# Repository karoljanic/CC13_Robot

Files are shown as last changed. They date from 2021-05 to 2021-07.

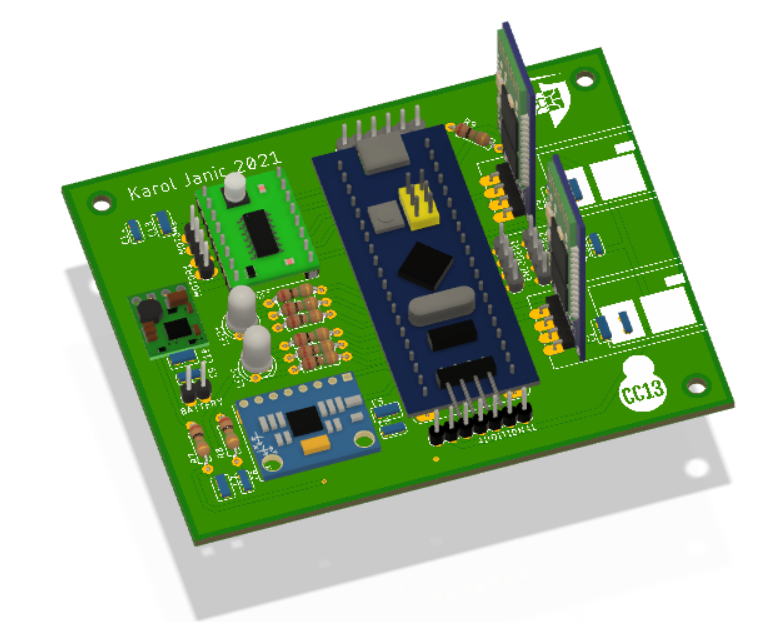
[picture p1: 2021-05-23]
CC13_ELECTRONICS/3DView.PNG

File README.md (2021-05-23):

# CC13_Robot
This is a robot project modeled on BB8. 
The construction is modelled in Autodesk Fusion 360 and printed using 3D printing technology. I currently use Creality Ender 3. 
The electronics is based on the STM21F1038C and self-made PCB / Arduino Nano 33 BLE Sense processor. 
The robot is controlled by a mobile app via Bluetooth. It is developed in Android Studio. 
Work still in progress.

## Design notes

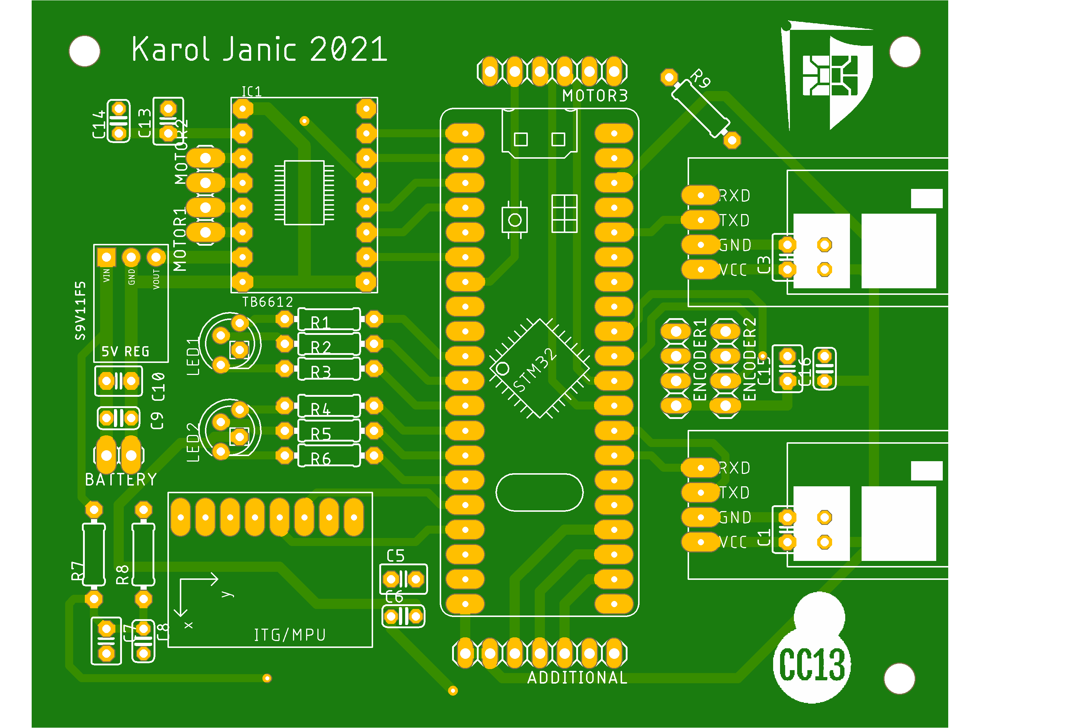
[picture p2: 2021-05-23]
CC13_ELECTRONICS/CC13.png

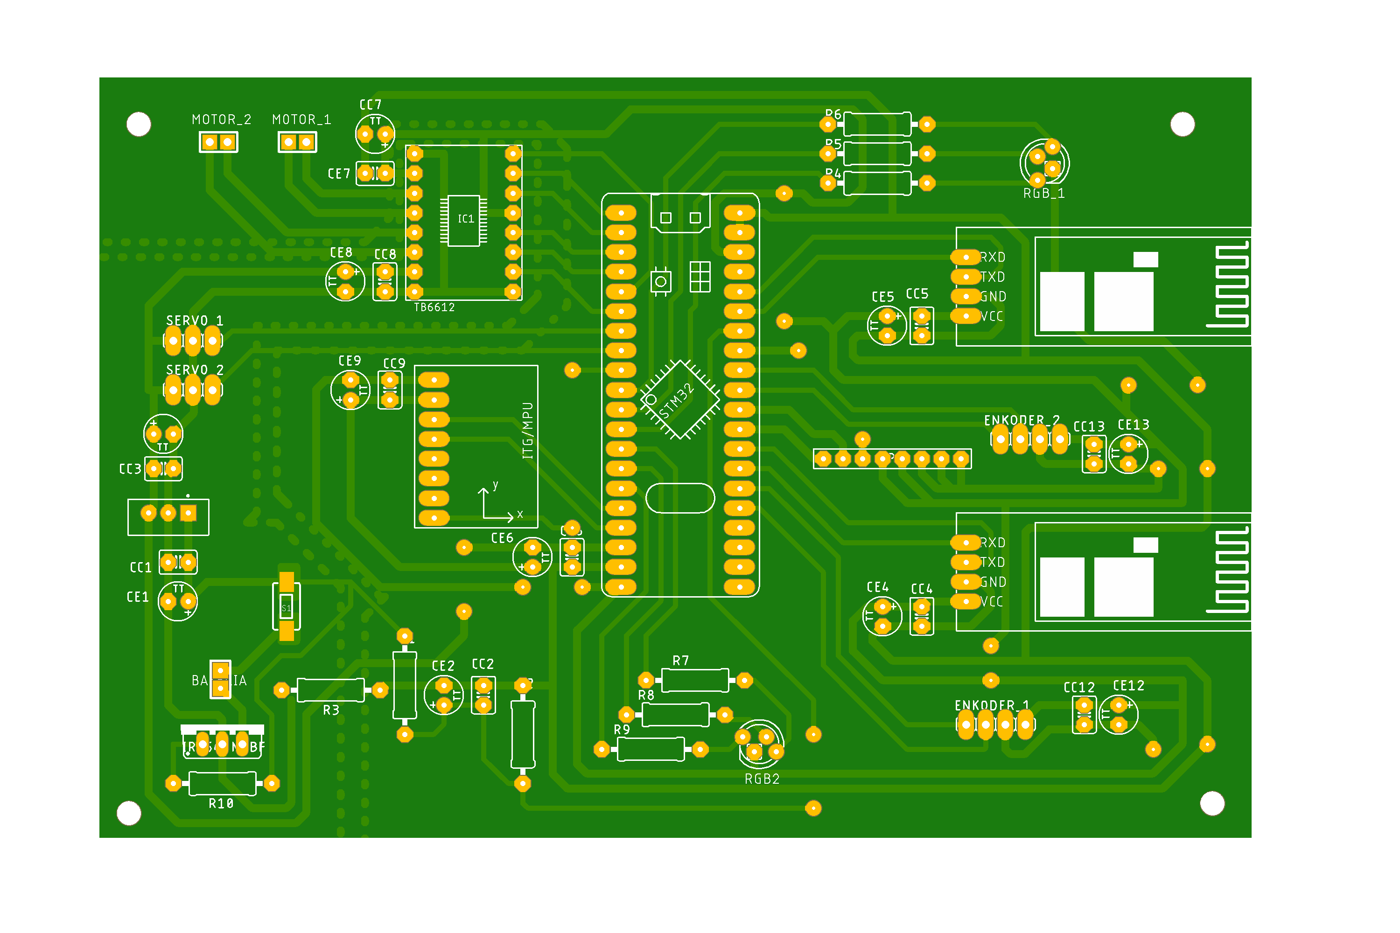
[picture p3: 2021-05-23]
CC13_ELECTRONICS/dokumenty/ModelPłytki.png

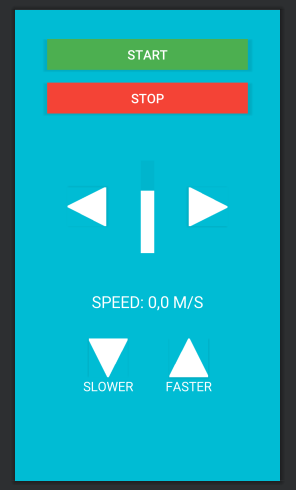
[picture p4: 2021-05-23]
CC13_MOBILE_APP/screeny_aplikacji/aplikacja_screen6.PNG

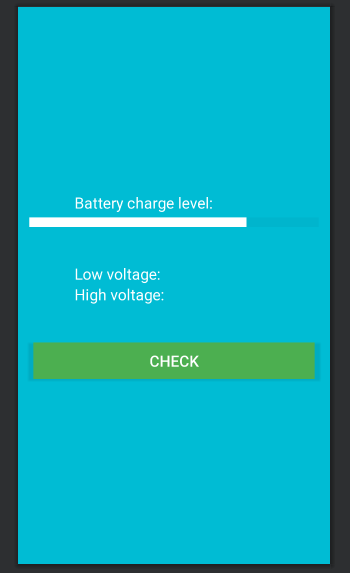
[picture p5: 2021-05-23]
CC13_MOBILE_APP/screeny_aplikacji/aplikacja_screen1.PNG

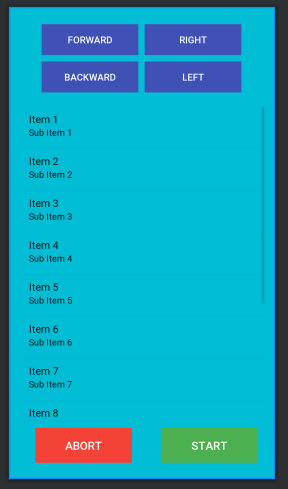
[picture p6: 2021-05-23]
CC13_MOBILE_APP/screeny_aplikacji/aplikacja_screen5.PNG

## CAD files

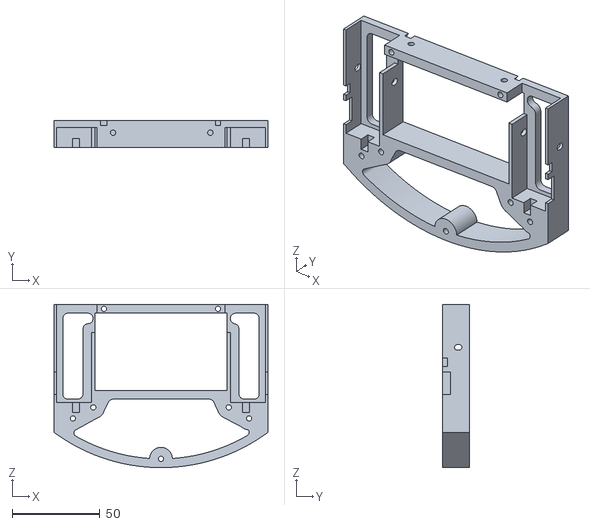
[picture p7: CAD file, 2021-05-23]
CC13_MECHANICS/CC13v7/part.1.II.v.7.stl
122.0 x 15.5 x 93.0

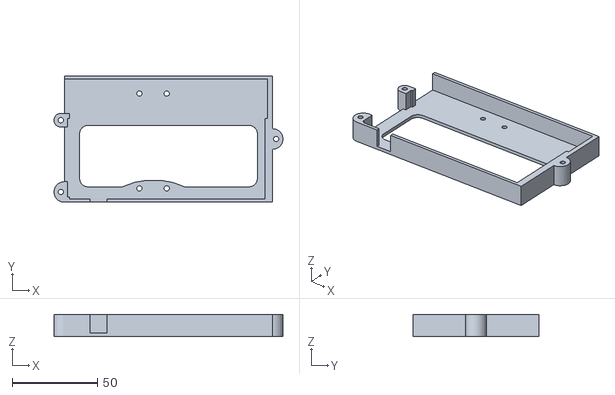
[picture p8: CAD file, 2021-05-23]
CC13_MECHANICS/CC13v7/part.1.c.I.v.7.stl
134.0 x 74.0 x 13.0

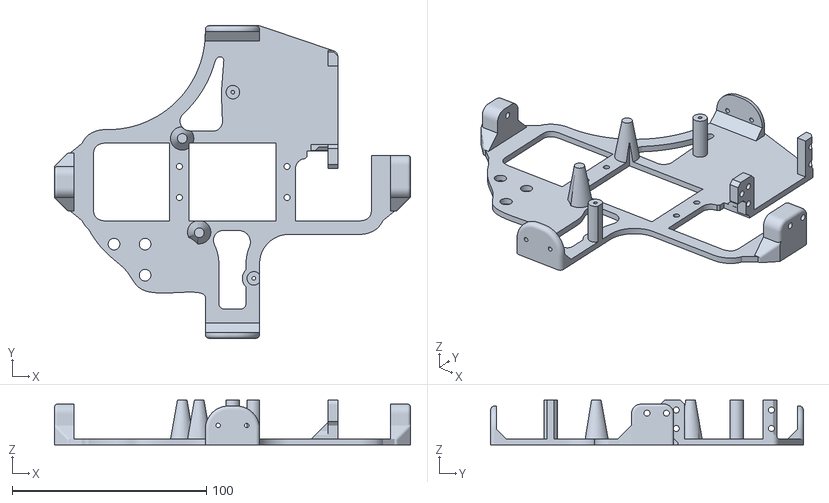
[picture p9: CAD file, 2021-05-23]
CC13_MECHANICS/CC13v7/part3.v.7.stl
183.3 x 161.0 x 23.0

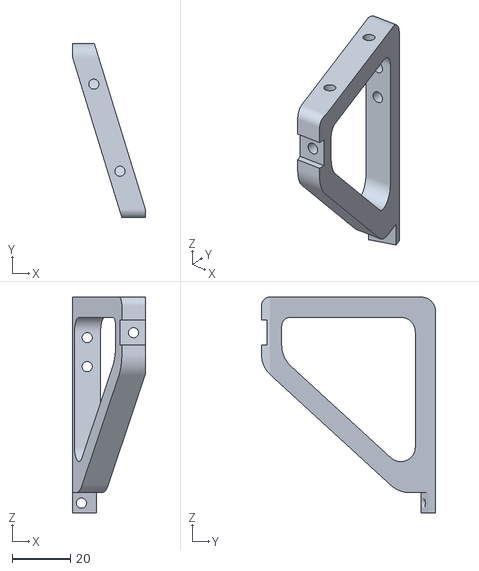
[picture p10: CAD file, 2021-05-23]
CC13_MECHANICS/CC13v7/okov6.stl
25.0 x 60.0 x 74.4

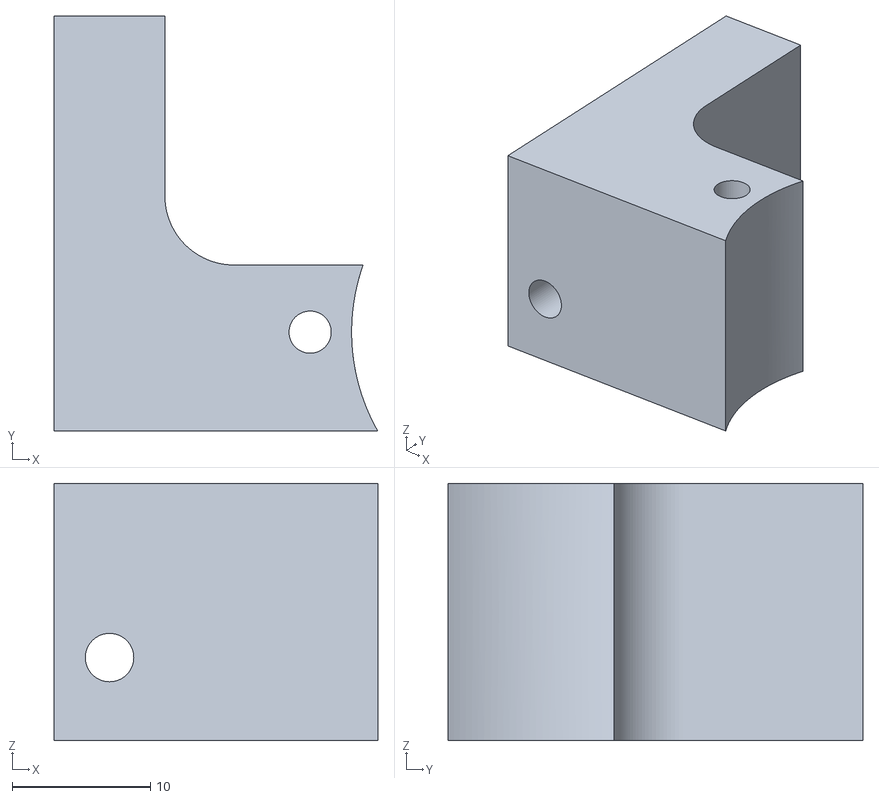
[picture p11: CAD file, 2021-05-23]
CC13_MECHANICS/CC13v7/Body3.stl
23.4 x 30.0 x 18.6

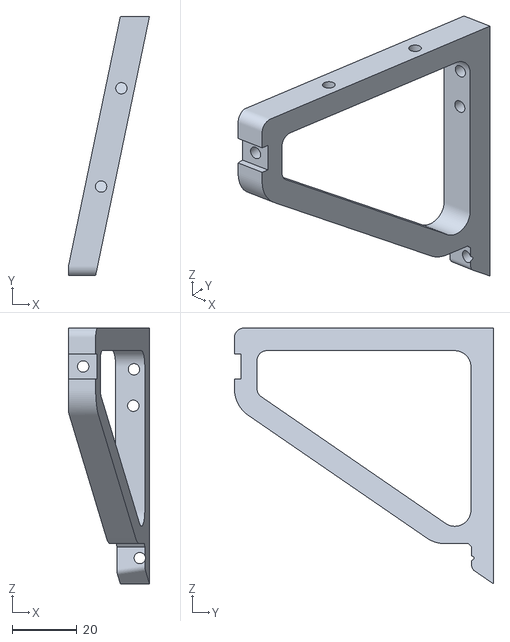
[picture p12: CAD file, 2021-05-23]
CC13_MECHANICS/CC13v7/Part2rev.stl
25.0 x 80.0 x 79.0

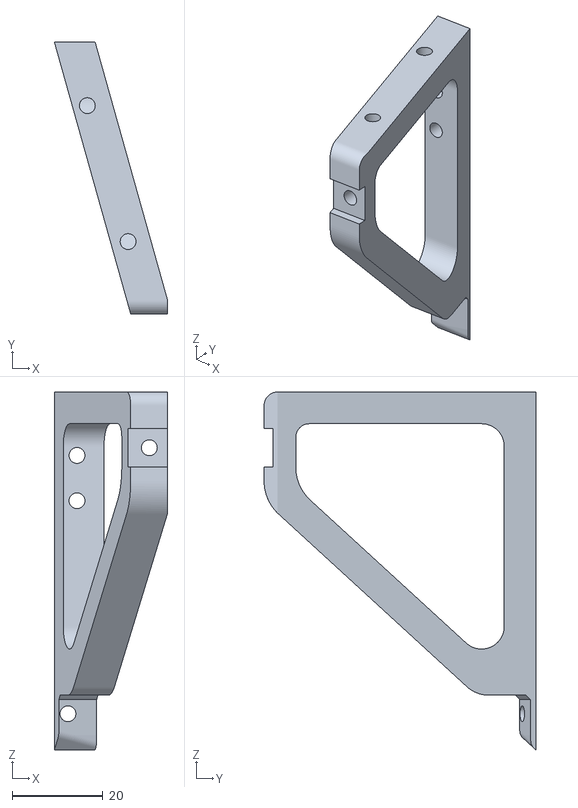
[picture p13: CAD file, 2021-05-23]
CC13_MECHANICS/CC13v7/Body1.stl
25.0 x 60.0 x 79.0

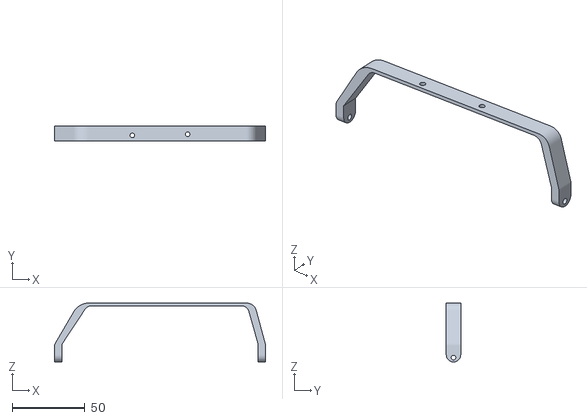
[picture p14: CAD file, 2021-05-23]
CC13_MECHANICS/CC13v7/part5.v.7.stl
145.0 x 10.0 x 40.5

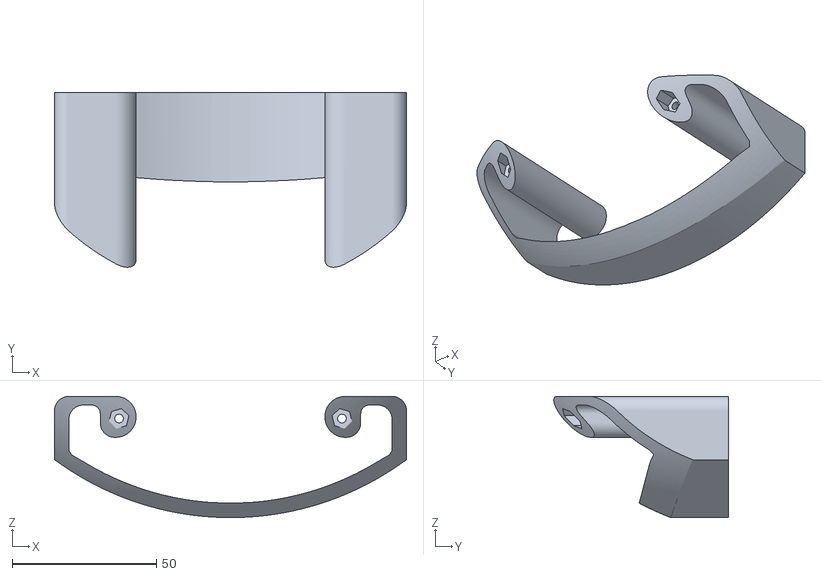
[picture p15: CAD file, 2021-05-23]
CC13_MECHANICS/CC13v7/part.4.v.7.stl
122.0 x 60.5 x 42.0

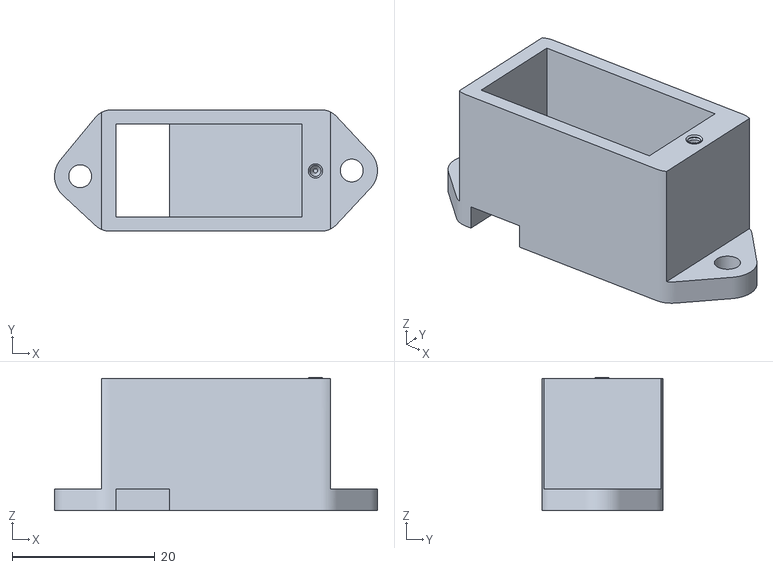
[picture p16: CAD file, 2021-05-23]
CC13_MECHANICS/CC13v7/part6.v.7.stl
45.2 x 17.0 x 18.6

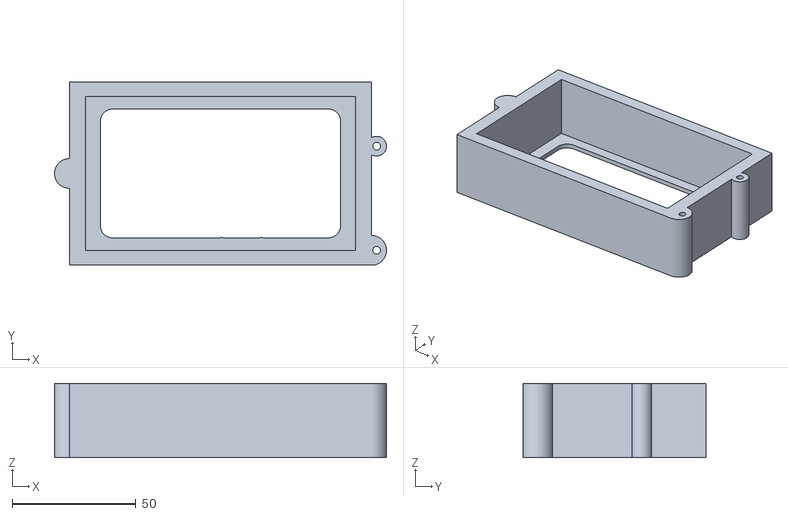
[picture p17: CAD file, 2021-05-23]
CC13_MECHANICS/CC13v7/part.1.c.II.v.7.stl
134.0 x 74.0 x 30.0

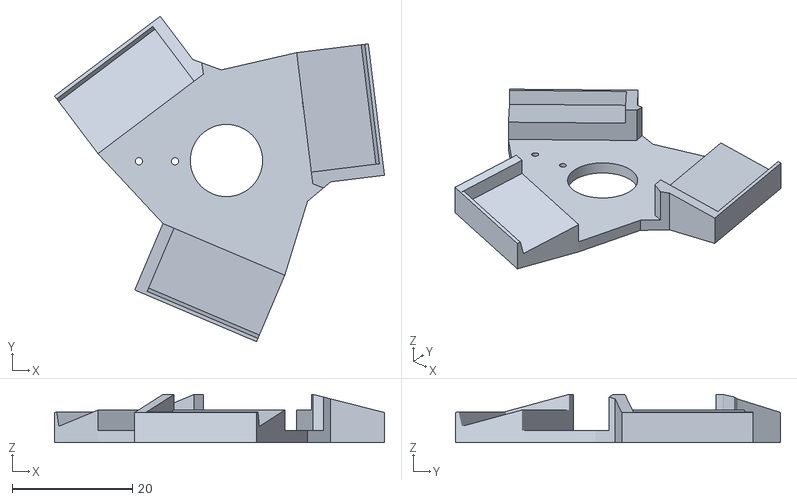
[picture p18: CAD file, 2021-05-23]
CC13_MECHANICS/CC13v7/part7.v.7.stl
54.8 x 54.1 x 8.00

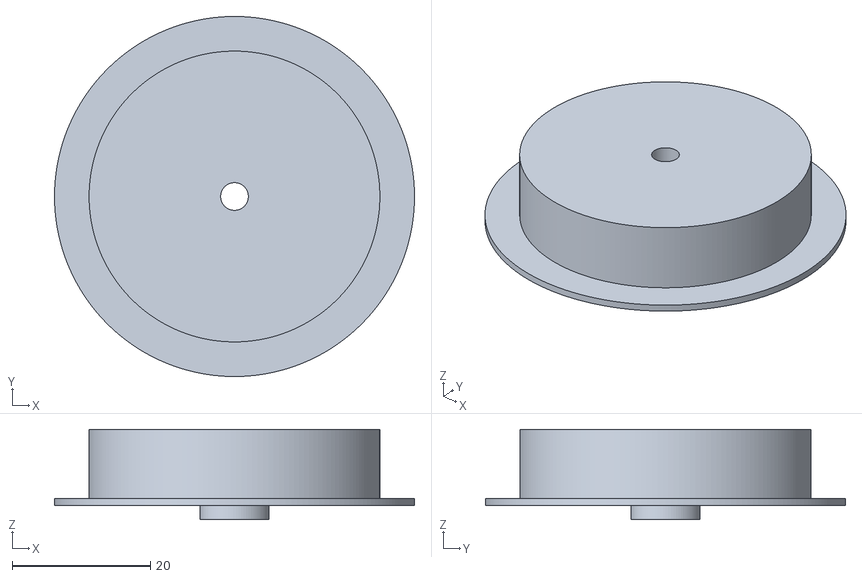
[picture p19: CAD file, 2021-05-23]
CC13_MECHANICS/CC13v7/felga.stl
52.0 x 52.0 x 13.0

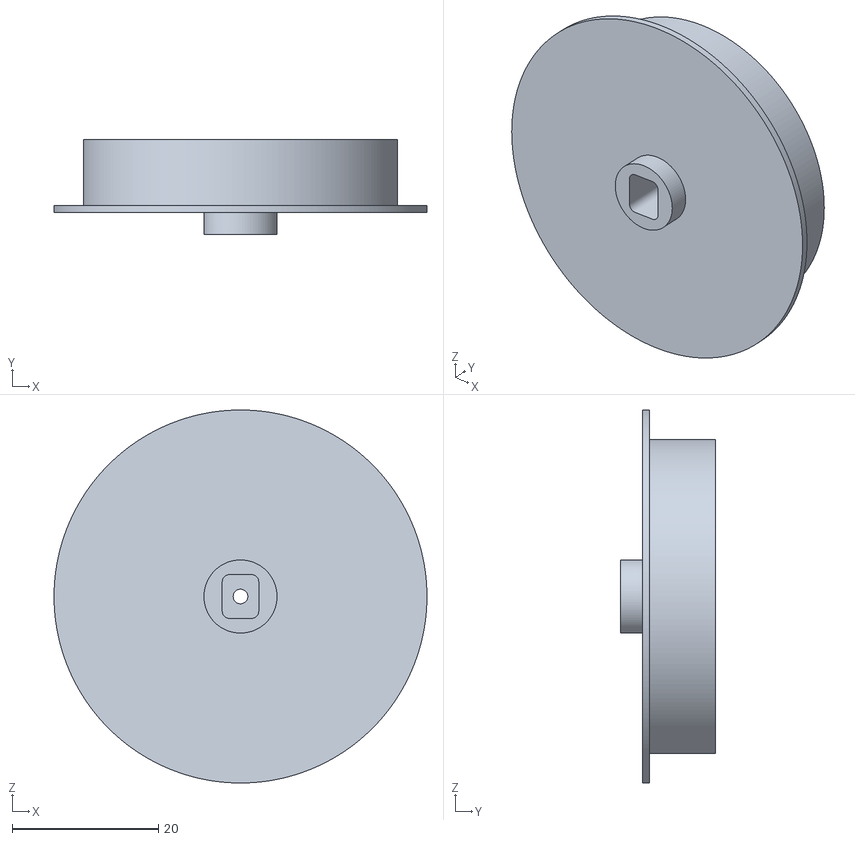
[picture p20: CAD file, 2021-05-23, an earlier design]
CC13_MECHANICS/CC13v7/part2.v.7.stl
51.0 x 13.0 x 51.0

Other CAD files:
CC13_MECHANICS/CC13v7/Body3rev.stl
CC13_MECHANICS/CC13v7/Part2 v16.stl
CC13_MECHANICS/CC13v7/Body2.stl
CC13_MECHANICS/CC13v7/part.1.I.v.7.stl

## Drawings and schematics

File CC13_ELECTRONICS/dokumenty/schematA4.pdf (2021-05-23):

## GND

## AGND

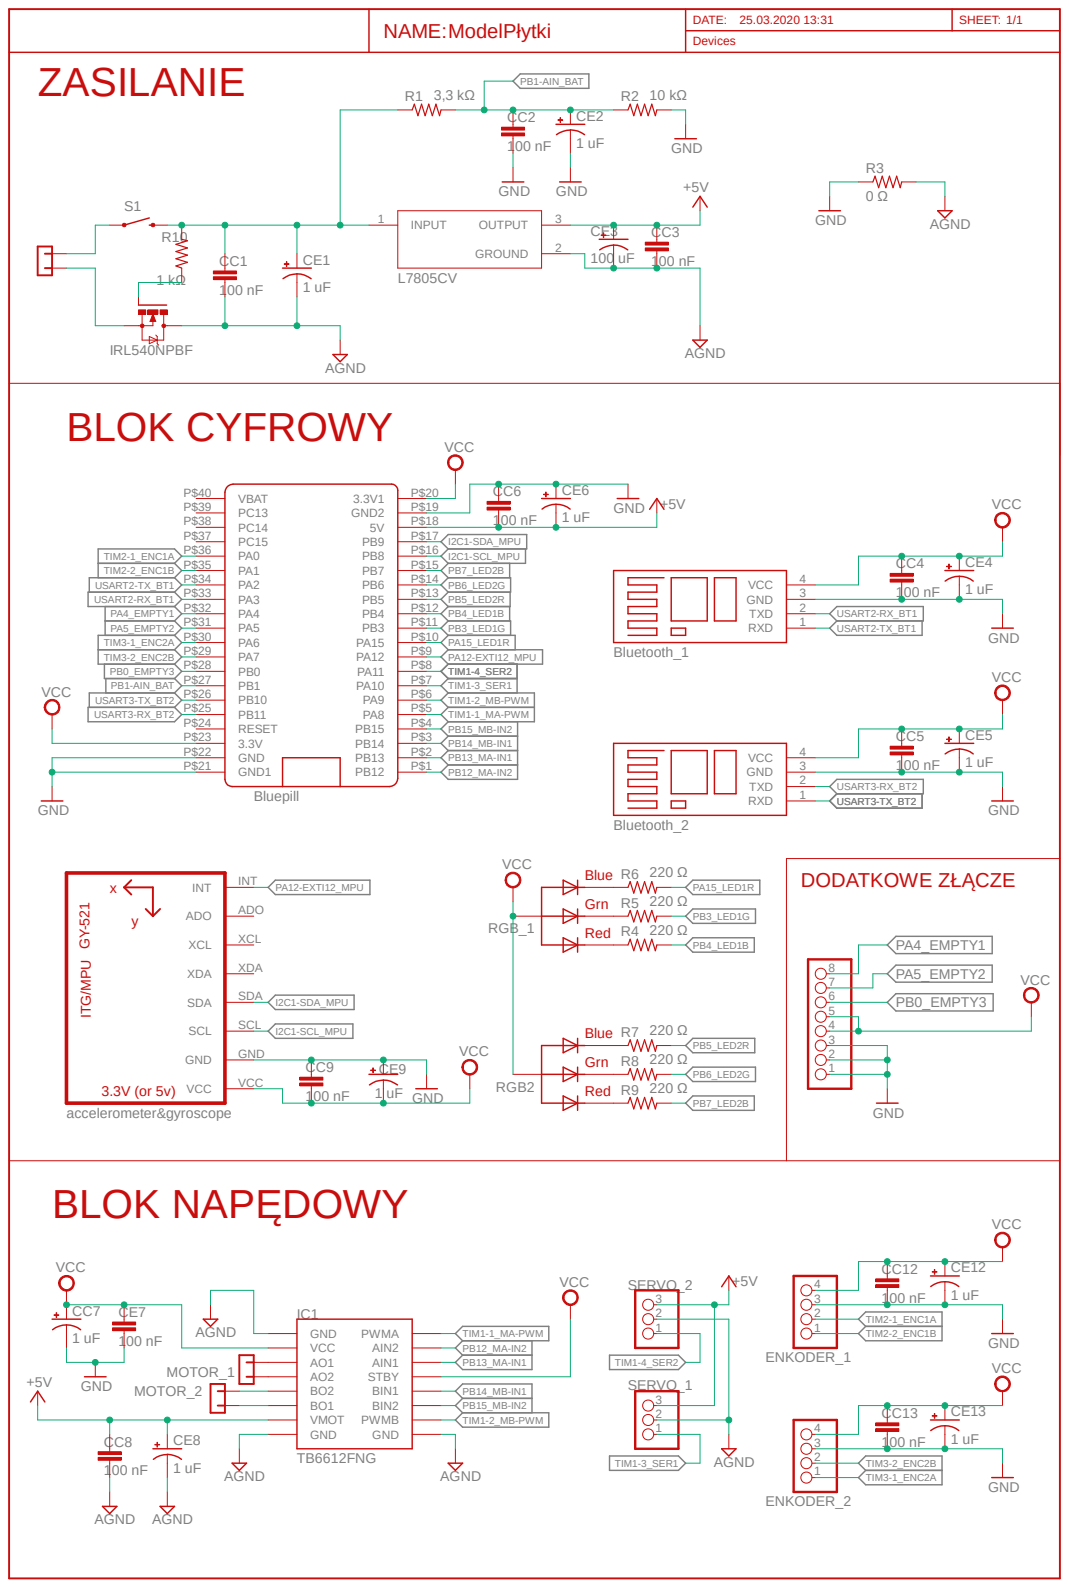
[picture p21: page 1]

DODATKOWE ZŁĄCZE GY⁻⁵²¹ ITG/MPU

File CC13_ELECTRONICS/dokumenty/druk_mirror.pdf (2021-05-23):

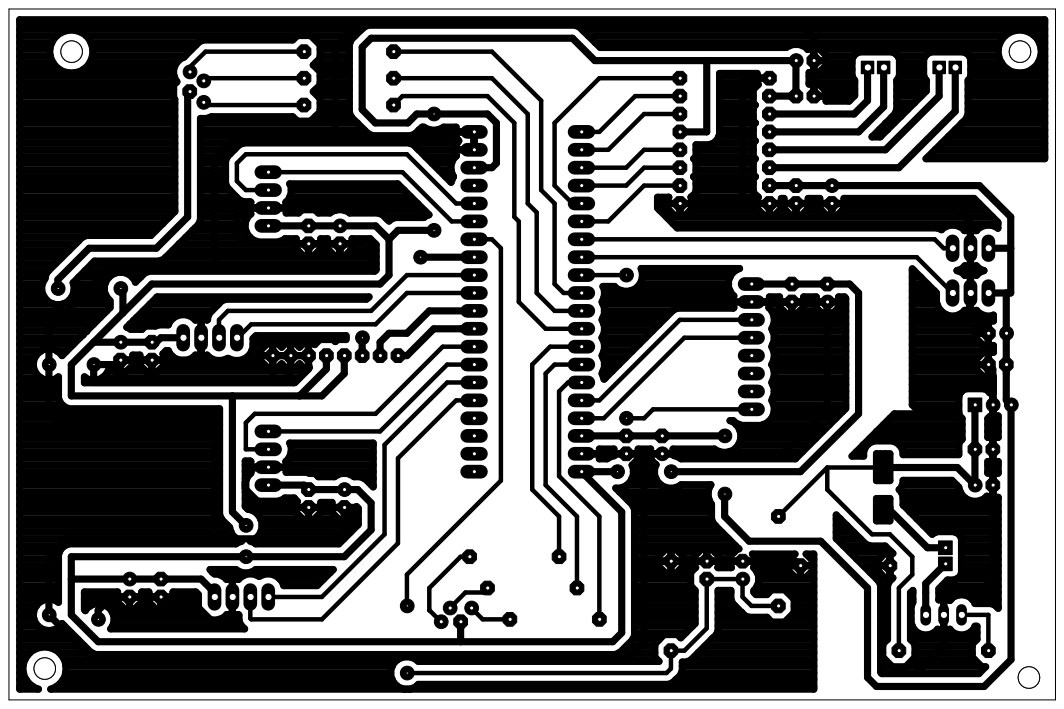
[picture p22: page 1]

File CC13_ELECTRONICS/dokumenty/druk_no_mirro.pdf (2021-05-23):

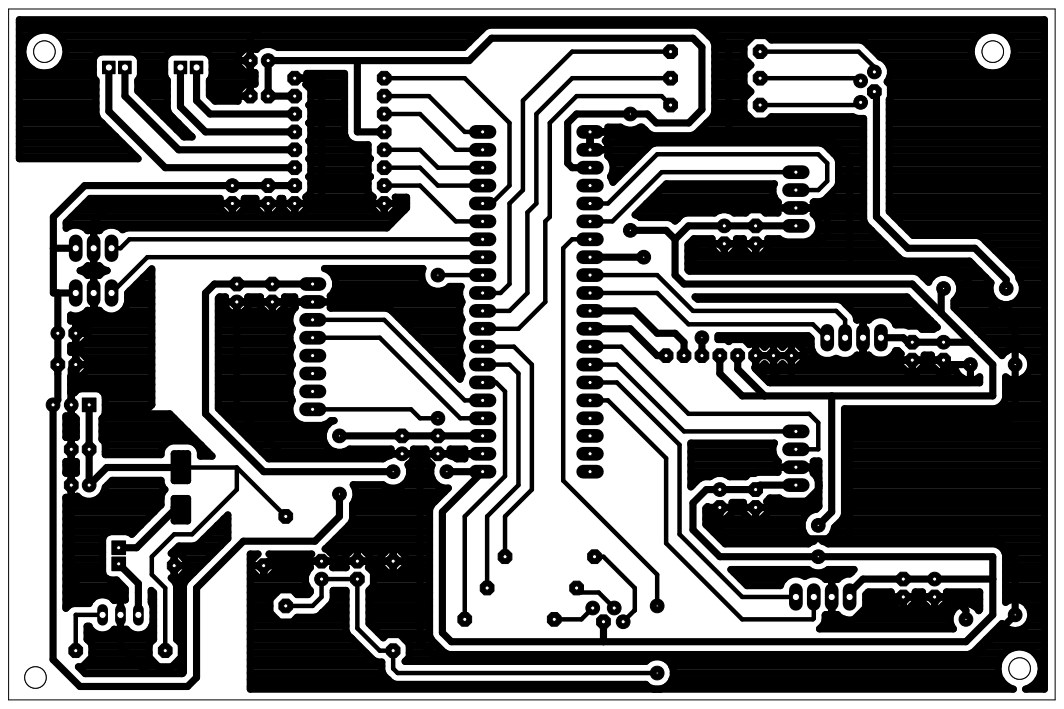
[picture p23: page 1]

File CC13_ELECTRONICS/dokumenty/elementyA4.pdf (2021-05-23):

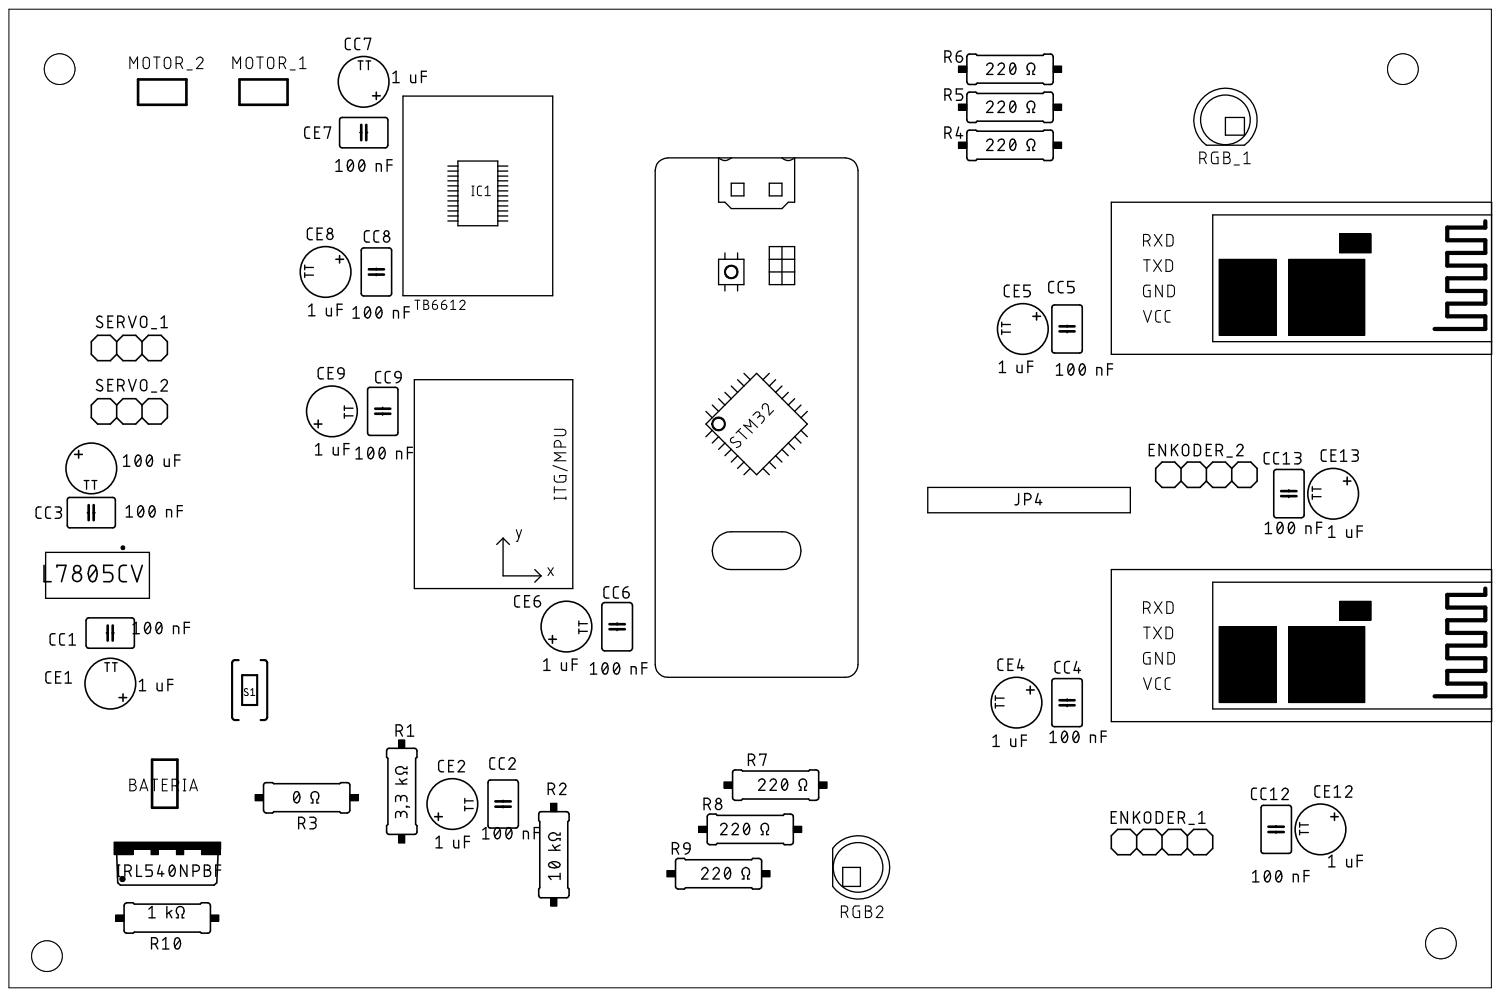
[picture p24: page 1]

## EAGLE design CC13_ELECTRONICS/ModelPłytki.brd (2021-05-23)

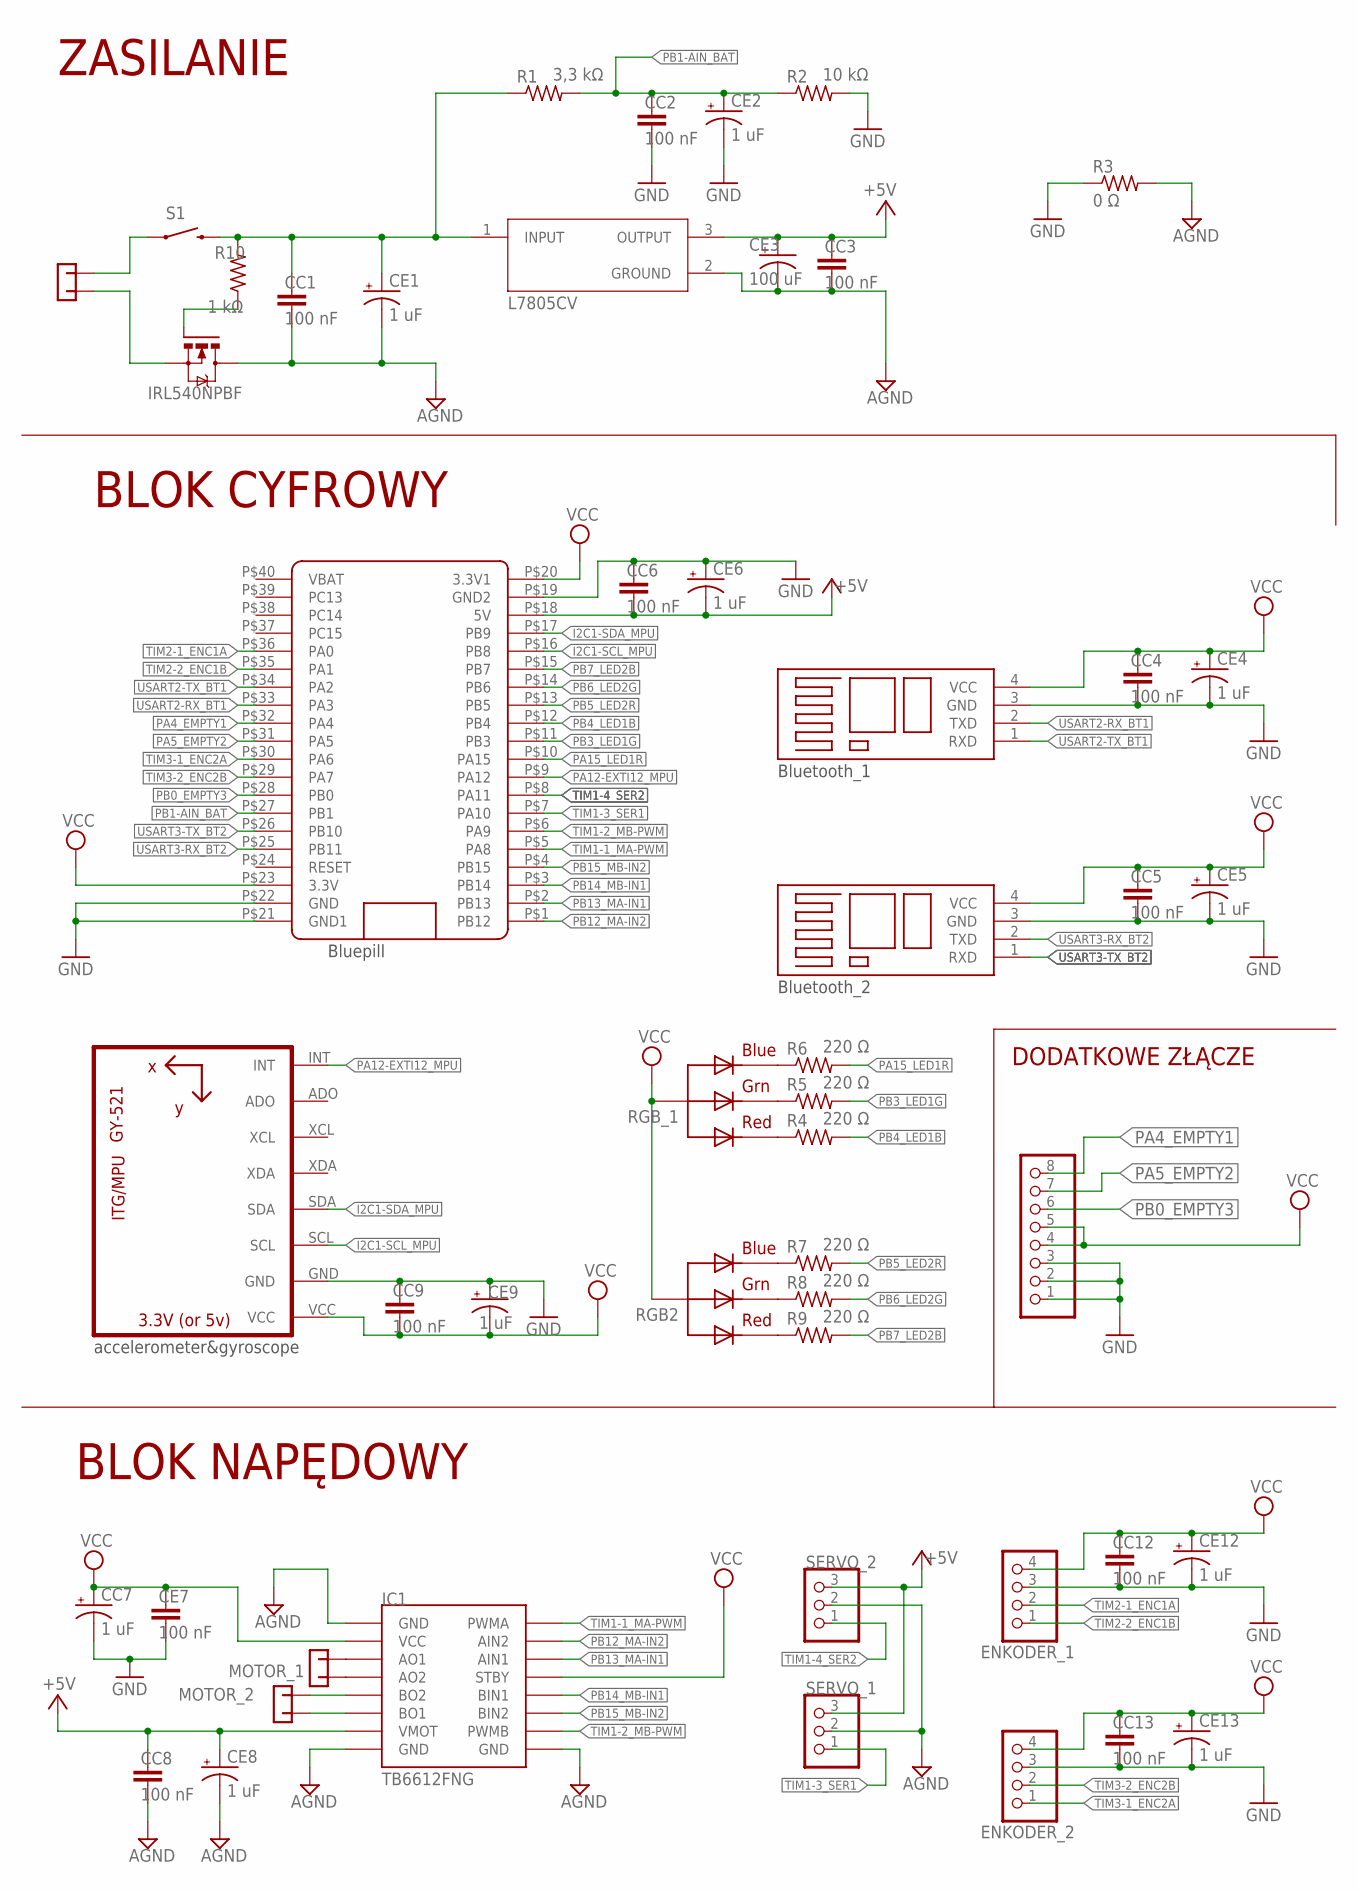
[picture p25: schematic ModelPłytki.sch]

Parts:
BATERIA: -CON2; CON2
BLUETOOTH2, BLUETOOTH3: BLUETOOTH
CC1, CC2, CC3, CC4, CC5, CC6, CC8, CC9, CC12, CC13: 100 nF; C025-030X050
CC7: 1 uF; TT2D5
CE1, CE2, CE4, CE5, CE6, CE8, CE9, CE12, CE13: 1 uF; TT2D5
CE3: 100 uF; TT2D5
CE7: 100 nF; C025-030X050
ENKODER_1, ENKODER_2: PINHD-1X4; 1X04
IC1: MODUL_POLOLU
IRL540NPBF: IRF520; TO220BV
JP4: PINHD-1X8BIG; 1X08-BIG
MOTOR_1, MOTOR_2: -CON2; CON2
R1: 3,3 kΩ; 0309/12
R2: 10 kΩ; 0309/12
R3: 0 Ω; 0309/12
R4, R5, R6, R7, R8, R9: 220 Ω; 0309/12
R10: 1 kΩ; 0309/12
RGB2: RGBLED_CA-5MM; LED5MMRGB
RGB_1: RGBLED_CA-5MM; LED5MMRGB
S1: RS032G05A3SM-SPST-MOMENTARY-SWSMD-1101NE; TACTILE-SWITCH-1101NE
SERVO_1, SERVO_2: PINHD-1X3; 1X03
U2: L7805CV; TO255P1040X460X1968-3
U4: GY-521MPU6050; GY-521
U$2: BLUE_PILL

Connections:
+5V: CC3.1, CC6.2, CC8.1, CE3.+, CE6.-, CE8.+, IC1.VMOT, SERVO_1.3, SERVO_2.3, U2.3 (OUTPUT), U$2.P$18 (5V)
AGND: CC1.2, CC3.2, CC8.2, CE1.-, CE3.-, CE8.-, IC1.GND1 (GND), IC1.GND2 (GND), IC1.GND3 (GND), IRL540NPBF.D, R3.2, SERVO_1.2, SERVO_2.2, U2.2 (GROUND)
GND: BLUETOOTH2.3 (GND), BLUETOOTH3.3 (GND), CC2.2, CC4.2, CC5.2, CC6.1, CC7.-, CC9.1, CC12.2, CC13.2, CE2.-, CE4.-, CE5.-, CE6.+, CE7.2, CE9.+, CE12.-, CE13.-, ENKODER_1.3, ENKODER_2.3, JP4.1, JP4.2, JP4.3, R2.2, R3.1, U4.GND, U$2.P$19 (GND2), U$2.P$21 (GND1), U$2.P$22 (GND)
I2C1-SCL_MPU: U4.SCL, U$2.P$16 (PB8)
I2C1-SDA_MPU: U4.SDA, U$2.P$17 (PB9)
unnamed: IRL540NPBF.G, R10.1
unnamed: IC1.BO2, MOTOR_2.P$1 (1)
unnamed: IC1.A02 (AO2), MOTOR_1.P$2 (2)
unnamed: IC1.BO1, MOTOR_2.P$2 (2)
unnamed: BATERIA.P$1 (1), S1.1
unnamed: R6.1, RGB_1.4 (BLUE)
unnamed: R5.1, RGB_1.3 (GREEN)
unnamed: R4.1, RGB_1.1 (RED)
unnamed: R8.1, RGB2.3 (GREEN)
unnamed: R7.1, RGB2.4 (BLUE)
unnamed: R9.1, RGB2.1 (RED)
unnamed: BATERIA.P$2 (2), IRL540NPBF.S
unnamed: IC1.AO1, MOTOR_1.P$1 (1)
unnamed: CC1.1, CE1.+, R1.1, R10.2, S1.2, U2.1 (INPUT)
PA4_EMPTY1: JP4.8, U$2.P$32 (PA4)
PA5_EMPTY2: JP4.7, U$2.P$31 (PA5)
PA12-EXTI12_MPU: U4.INT, U$2.P$9 (PA12)
PA15_LED1R: R6.2, U$2.P$10 (PA15)
PB0_EMPTY3: JP4.6, U$2.P$28 (PB0)
PB1-AIN_BAT: CC2.1, CE2.+, R1.2, R2.1, U$2.P$27 (PB1)
PB3_LED1G: R5.2, U$2.P$11 (PB3)
PB4_LED1B: R4.2, U$2.P$12 (PB4)
PB5_LED2R: R7.2, U$2.P$13 (PB5)
PB6_LED2G: R8.2, U$2.P$14 (PB6)
PB7_LED2B: R9.2, U$2.P$15 (PB7)
PB12_MA-IN2: IC1.AIN2, U$2.P$1 (PB12)
PB13_MA-IN1: IC1.AIN1, U$2.P$2 (PB13)
PB14_MB-IN1: IC1.BIN1, U$2.P$3 (PB14)
PB15_MB-IN2: IC1.BIN2, U$2.P$4 (PB15)
TIM1-1_MA-PWM: IC1.PWMA, U$2.P$5 (PA8)
TIM1-2_MB-PWM: IC1.PWMB, U$2.P$6 (PA9)
TIM1-3_SER1: SERVO_1.1, U$2.P$7 (PA10)
TIM1-4_SER2: SERVO_2.1, U$2.P$8 (PA11)
TIM2-1_ENC1A: ENKODER_1.2, U$2.P$36 (PA0)
TIM2-2_ENC1B: ENKODER_1.1, U$2.P$35 (PA1)
TIM3-1_ENC2A: ENKODER_2.1, U$2.P$30 (PA6)
TIM3-2_ENC2B: ENKODER_2.2, U$2.P$29 (PA7)
USART2-RX_BT1: BLUETOOTH2.2 (TXD), U$2.P$33 (PA3)
USART2-TX_BT1: BLUETOOTH2.1 (RXD), U$2.P$34 (PA2)
USART3-RX_BT2: BLUETOOTH3.2 (TXD), U$2.P$25 (PB11)
USART3-TX_BT2: BLUETOOTH3.1 (RXD), U$2.P$26 (PB10)
VCC: BLUETOOTH2.4 (VCC), BLUETOOTH3.4 (VCC), CC4.1, CC5.1, CC7.+, CC9.2, CC12.1, CC13.1, CE4.+, CE5.+, CE7.1, CE9.-, CE12.+, CE13.+, ENKODER_1.4, ENKODER_2.4, IC1.STBY, IC1.VCC, JP4.4, JP4.5, RGB2.2 (VCC), RGB_1.2 (VCC), U4.VCC, U$2.P$20 (3.3V1), U$2.P$23 (3.3V)

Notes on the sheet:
ZASILANIE
BLOK CYFROWY
BLOK NAPĘDOWY
Bluetooth_1
Bluetooth_2
Bluepill
accelerometer&gyroscope
DODATKOWE ZŁĄCZE

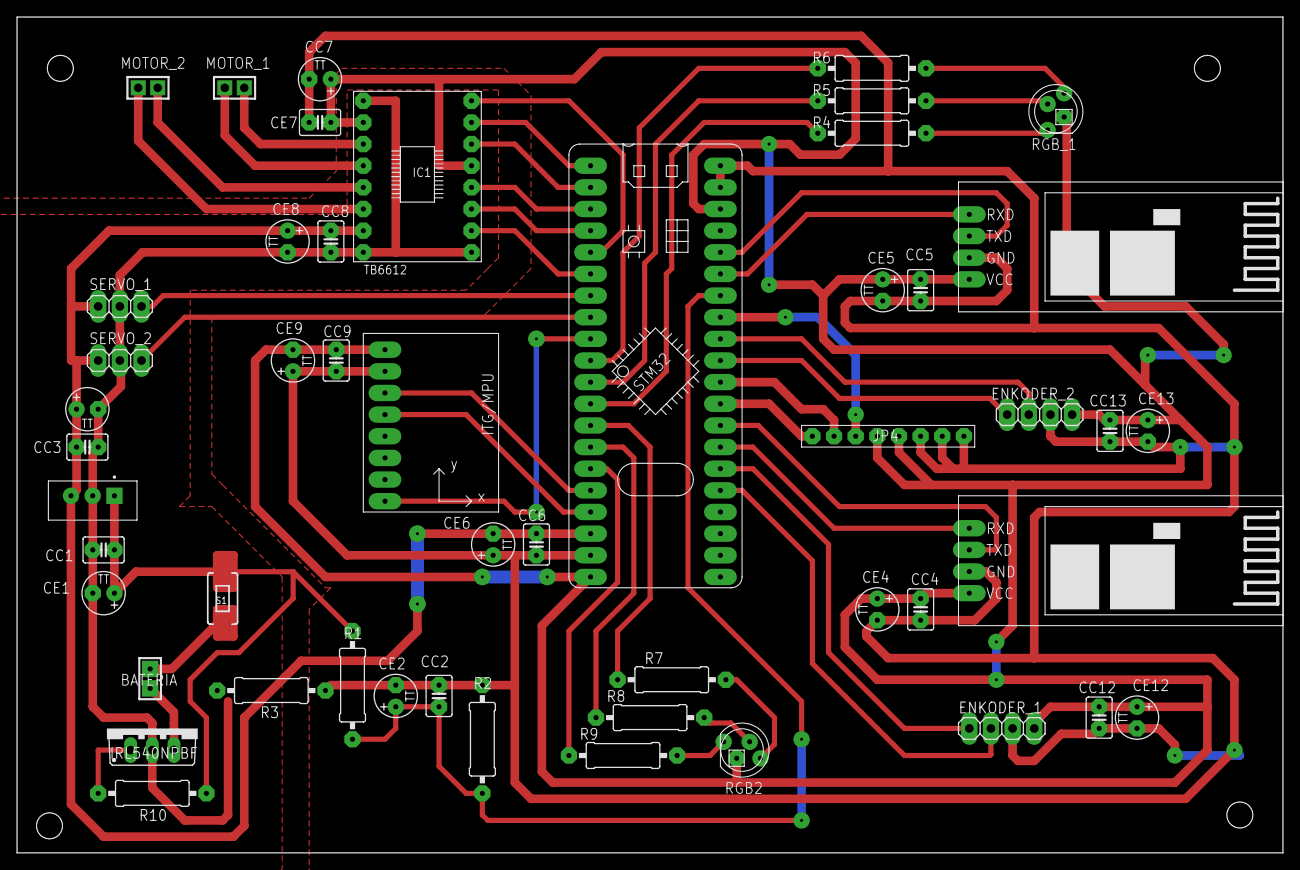
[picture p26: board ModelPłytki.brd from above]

Board: 2 copper layers, 148.6 x 98.1 mm, 50 parts (0 on the bottom side), 47 nets.

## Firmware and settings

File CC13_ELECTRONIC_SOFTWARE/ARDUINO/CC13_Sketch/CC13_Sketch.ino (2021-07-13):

#include <ArduinoBLE.h>       // Bluetooth Low Energy
#include <Arduino_LSM9DS1.h>  // Accelerometer, Gyroscope, Magnetometer
#include <Arduino_HTS221.h>   // Thermometer, Humidity meter 

// define used pins 
#define MOTOR_PWM_A    P0_4
#define MOTOR_PWM_B    P0_5
#define MOTOR_IN_1_A   P1_11
#define MOTOR_IN_2_A   P1_12
#define MOTOR_IN_1_B   P1_15
#define MOTOR_IN_2_B   P1_13

#define ENCODER_INC_A  P1_14
#define ENCODER_DEC_A  P0_30
#define ENCODER_INC_B  P0_23
#define ENCODER_DEC_B  P0_29

#define STEPPER_IN1    P0_21
#define STEPPER_IN2    P0_27
#define STEPPER_IN3    P1_2
#define STEPPER_IN4    P0_31

#define LED_R          P0_3
#define LED_G          P0_28
#define LED_B          P0_2

#define BATTERY_CONTROL   1
#define DRIVE_CONTROL     2
#define SPEED_CONTROL     3
#define DISTANCE_CONTROL  4
#define LIVE_CONTROL      5


// definition of variables
// variables used to reading
int   old_battery_level;      // percentages
float temperature,            // Celsius degrees
      humidity,               // percentages
      ac_x, ac_y, ac_z,       // g(meter/second^2)
      gy_x, gy_y, gy_z,       // degrees/second
      mag_x, mag_y, mag_z;    // micro Tesla(uT)
      
// variable used to checking current activity in app
int manage;

// variables used to time counting
long current_millis, previous_millis = 0;

// variables used to encoders reading
long pulse_encA_up = 0, pulse_encA_down = 0, pulse_encB_up = 0, pulse_encB_down = 0;

// variables used to stepper motor setting 
int steps_to_do = 4095;
int current_steps = 0;
bool stepper_direction = true;

// variables used to ... 


// BLE Services and Characteristices
BLEService ManageService("b3926802-cf6f-11eb-b8bc-0242ac130003");
BLEService HTSService("44214a98-c442-11eb-8529-0242ac130003");
BLEService IMUService("44214d04-c442-11eb-8529-0242ac130003");
BLEService DriveControlService("118ef412-ccef-11eb-b8bc-0242ac130003");
BLEService SpeedControlService("118ef66a-ccef-11eb-b8bc-0242ac130003");
BLEService DistanceControlService("118ef778-ccef-11eb-b8bc-0242ac130003");
BLEService LiveControlService("118ef872-ccef-11eb-b8bc-0242ac130003");

BLEShortCharacteristic manage_short("c0c2673e-cf6f-11eb-b8bc-0242ac130003", BLEWrite);

BLEShortCharacteristic battery_short("1ad84f14-c443-11eb-8529-0242ac130003", BLERead | BLENotify);
BLEShortCharacteristic temperature_short("1ad8514e-c443-11eb-8529-0242ac130003", BLERead | BLENotify);
BLEShortCharacteristic humidity_short("1ad85234-c443-11eb-8529-0242ac130003", BLERead | BLENotify);

BLEFloatCharacteristic ac_x_float("66b888d0-c444-11eb-8529-0242ac130003", BLERead | BLENotify);
BLEFloatCharacteristic ac_y_float("66b88b00-c444-11eb-8529-0242ac130003", BLERead | BLENotify);
BLEFloatCharacteristic ac_z_float("66b88bfa-c444-11eb-8529-0242ac130003", BLERead | BLENotify);

BLEFloatCharacteristic gy_x_float("66b88ccc-c444-11eb-8529-0242ac130003", BLERead | BLENotify);
BLEFloatCharacteristic gy_y_float("66b88d94-c444-11eb-8529-0242ac130003", BLERead | BLENotify);
BLEFloatCharacteristic gy_z_float("66b88f2e-c444-11eb-8529-0242ac130003", BLERead | BLENotify);

BLEFloatCharacteristic mag_x_float("66b89000-c444-11eb-8529-0242ac130003", BLERead | BLENotify);
BLEFloatCharacteristic mag_y_float("66b890b4-c444-11eb-8529-0242ac130003", BLERead | BLENotify);
BLEFloatCharacteristic mag_z_float("66b89172-c444-11eb-8529-0242ac130003", BLERead | BLENotify);

BLEShortCharacteristic rgb1_short("47eb805c-ccef-11eb-b8bc-0242ac130003", BLEWrite);
BLEShortCharacteristic rgb2_short("47eb8296-ccef-11eb-b8bc-0242ac130003", BLEWrite);
BLEUnsignedIntCharacteristic joy1_unsigned_int("47eb8386-ccef-11eb-b8bc-0242ac130003", BLEWrite);
BLEUnsignedIntCharacteristic joy2_unsigned_int("47eb857a-ccef-11eb-b8bc-0242ac130003", BLEWrite);

BLEShortCharacteristic speed_short("e04bc9fe-cf3f-11eb-b8bc-0242ac130003", BLEWrite);
BLEShortCharacteristic direction_short("e04bcc74-cf3f-11eb-b8bc-0242ac130003", BLEWrite);

BLEStringCharacteristic route_string("e8331bc2-cf3f-11eb-b8bc-0242ac130003", BLEWrite, 36);
BLEShortCharacteristic abort_short("e8331df2-cf3f-11eb-b8bc-0242ac130003", BLEWrite);

BLEShortCharacteristic joy1_x_v2_short("edaee266-cf3f-11eb-b8bc-0242ac130003", BLEWrite);
BLEShortCharacteristic joy1_y_v2_short("edaee4dc-cf3f-11eb-b8bc-0242ac130003", BLEWrite);
BLEShortCharacteristic joy2_x_v2_short("edaee5c2-cf3f-11eb-b8bc-0242ac130003", BLEWrite);
BLEShortCharacteristic joy2_y_v2_short("edaee680-cf3f-11eb-b8bc-0242ac130003", BLEWrite);


// Initialization of all used sensors
// returns number of uninitiated devices
int sensor_initialization(){
    int result = 0;
    
    if(!HTS.begin()){
        Serial.println("Failed to initialize HTS221!");
        result++;
    }else{
        Serial.println("HTS221 initialized correctly!");
    }

    if(!IMU.begin()){
        Serial.println("Failed to start LSM9DS1!");
        result++;
    }else{
        Serial.println("LSM9DS1 initialized correctly!");
    }

    return result;
}

// Initialization of Bluetooth Low Energy 
// returns number of errors
int BLE_initialization(){

    if (!BLE.begin()){
        Serial.println("Failed to start BLE!");
        return 1;
    }else{
        Serial.println("BLE initialized correctly!");
    }

    BLE.setLocalName("CC13");

    BLE.setAdvertisedService(ManageService);
    BLE.setAdvertisedService(HTSService); 
    BLE.setAdvertisedService(IMUService);
    BLE.setAdvertisedService(DriveControlService);
    BLE.setAdvertisedService(SpeedControlService);
    BLE.setAdvertisedService(DistanceControlService);
    BLE.setAdvertisedService(LiveControlService);

    ManageService.addCharacteristic(manage_short);
     
    HTSService.addCharacteristic(battery_short); 
    HTSService.addCharacteristic(temperature_short); 
    HTSService.addCharacteristic(humidity_short); 

    IMUService.addCharacteristic(ac_x_float); 
    IMUService.addCharacteristic(ac_y_float); 
    IMUService.addCharacteristic(ac_z_float); 
    IMUService.addCharacteristic(gy_x_float); 
    IMUService.addCharacteristic(gy_y_float); 
    IMUService.addCharacteristic(gy_z_float); 
    IMUService.addCharacteristic(mag_x_float); 
    IMUService.addCharacteristic(mag_y_float); 
    IMUService.addCharacteristic(mag_z_float); 

    DriveControlService.addCharacteristic(rgb1_short);
    DriveControlService.addCharacteristic(rgb2_short);
    DriveControlService.addCharacteristic(joy1_unsigned_int);
    DriveControlService.addCharacteristic(joy2_unsigned_int);

    SpeedControlService.addCharacteristic(speed_short);
    SpeedControlService.addCharacteristic(direction_short);

    DistanceControlService.addCharacteristic(route_string);
    DistanceControlService.addCharacteristic(abort_short);

    LiveControlService.addCharacteristic(joy1_x_v2_short);
    LiveControlService.addCharacteristic(joy1_y_v2_short);
    LiveControlService.addCharacteristic(joy2_x_v2_short);
    LiveControlService.addCharacteristic(joy2_y_v2_short);
    
    BLE.addService(ManageService);
    BLE.addService(HTSService); 
    BLE.addService(IMUService); 
    BLE.addService(DriveControlService);
    BLE.addService(SpeedControlService);
    BLE.addService(DistanceControlService);
    BLE.addService(LiveControlService);
    
    battery_short.writeValue(67);
    temperature_short.writeValue(23);
    humidity_short.writeValue(44);
    ac_x_float.writeValue(0.0);
    ac_y_float.writeValue(0.0);
    ac_z_float.writeValue(0.0);
    gy_x_float.writeValue(0.0);
    gy_y_float.writeValue(0.0);
    gy_z_float.writeValue(0.0);
    mag_x_float.writeValue(0.0);
    mag_y_float.writeValue(0.0);
    mag_z_float.writeValue(0.0);

    BLE.advertise();
    
    return 0;
}

// reads voltage and maps it on range 0-100%
void read_battery_level(){
    int battery = analogRead(A0);
    int battery_level = map(battery, 0, 1023, 0, 100);

    if(battery_level != old_battery_level){     
        battery_short.writeValue(battery_level); 
        old_battery_level = battery_level;       
    }
}

// reads values from HTS sensor
void readHTS(){
    temperature = HTS.readTemperature();
    humidity    = HTS.readHumidity();

    temperature_short.writeValue((short)temperature);
    humidity_short.writeValue((short)humidity);
}

// reads values from IMU sensor
void read_IMU(){
    if(IMU.accelerationAvailable()){
        IMU.readAcceleration(ac_x, ac_y, ac_z);
    }
    ac_x_float.writeValue(ac_x);
    ac_y_float.writeValue(ac_y);
    ac_z_float.writeValue(ac_z);

    if(IMU.gyroscopeAvailable()){
        IMU.readGyroscope(gy_x, gy_y, gy_z);
    }
    gy_x_float.writeValue(gy_x);
    gy_y_float.writeValue(gy_y);
    gy_z_float.writeValue(gy_z);

    if(IMU.magneticFieldAvailable()){
        IMU.readMagneticField(mag_x, mag_y, mag_z); 
    }    
    mag_x_float.writeValue(mag_x);
    mag_y_float.writeValue(mag_y);
    mag_z_float.writeValue(mag_z);
}

// converts byte array value to long long value
long long byte_array_to_long_long(long long x){
    // int m = ( (2<<7) - 1);
    int m = 255;
    long long result = 0;
    for(int i = 0; i<4; i++)
    {
        result <<= 8;
        result += (x&m);
        x >>= 8;
    }
    return result;
}

// functions used in encoder interrupts 
void encoderup_A(){
    pulse_encA_up++;
}

void encoderdown_A(){
    pulse_encA_down++;
}

void encoderup_B(){
    pulse_encB_up++;
}

void encoderdown_B(){
    pulse_encB_down++;
}

// sets work-parameter for stepper motor
void set_stepper(){
    if(stepper_direction == 1){
        current_steps++;}
    if(stepper_direction == 0){
        current_steps--;}
    if(current_steps>7){
        current_steps=0;}
    if(current_steps<0){
        current_steps=7;}
}

// sets an appropriate output signal for the stepper motor
void stepper(int xw){
    for (int x=0;x<xw;x++){
      switch(current_steps){
         case 0:
           digitalWrite(STEPPER_IN1, LOW); 
           digitalWrite(STEPPER_IN2, LOW);
           digitalWrite(STEPPER_IN3, LOW);
           digitalWrite(STEPPER_IN4, HIGH);
         break; 
         case 1:
           digitalWrite(STEPPER_IN1, LOW); 
           digitalWrite(STEPPER_IN2, LOW);
           digitalWrite(STEPPER_IN3, HIGH);
           digitalWrite(STEPPER_IN4, HIGH);
         break; 
         case 2:
           digitalWrite(STEPPER_IN1, LOW); 
           digitalWrite(STEPPER_IN2, LOW);
           digitalWrite(STEPPER_IN3, HIGH);
           digitalWrite(STEPPER_IN4, LOW);
         break; 
         case 3:
           digitalWrite(STEPPER_IN1, LOW); 
           digitalWrite(STEPPER_IN2, HIGH);
           digitalWrite(STEPPER_IN3, HIGH);
           digitalWrite(STEPPER_IN4, LOW);
         break; 
         case 4:
           digitalWrite(STEPPER_IN1, LOW); 
           digitalWrite(STEPPER_IN2, HIGH);
           digitalWrite(STEPPER_IN3, LOW);
           digitalWrite(STEPPER_IN4, LOW);
         break; 
         case 5:
           digitalWrite(STEPPER_IN1, HIGH); 
           digitalWrite(STEPPER_IN2, HIGH);
           digitalWrite(STEPPER_IN3, LOW);
           digitalWrite(STEPPER_IN4, LOW);
         break; 
           case 6:
           digitalWrite(STEPPER_IN1, HIGH); 
           digitalWrite(STEPPER_IN2, LOW);
           digitalWrite(STEPPER_IN3, LOW);
           digitalWrite(STEPPER_IN4, LOW);
         break; 
         case 7:
           digitalWrite(STEPPER_IN1, HIGH); 
           digitalWrite(STEPPER_IN2, LOW);
           digitalWrite(STEPPER_IN3, LOW);
           digitalWrite(STEPPER_IN4, HIGH);
         break; 
         default:
           digitalWrite(STEPPER_IN1, LOW); 
           digitalWrite(STEPPER_IN2, LOW);
           digitalWrite(STEPPER_IN3, LOW);
           digitalWrite(STEPPER_IN4, LOW);
         break; 
       }
       set_stepper();
    }
} 

void set_motors(){
  
}

void set_head(){
  
}

void set_leds(){
  
}

void change_speed(){

    Serial.println(speed_short.value());
    Serial.println(direction_short.value());
    Serial.println("");
}

void do_route(){
    String s = route_string.value();
    Serial.println(s);
 
}

void off_all(){
  
}

void setup(){
    Serial.begin(9600);  
    //while (!Serial);

    pinMode(LED_BUILTIN, OUTPUT);

    pinMode(STEPPER_IN1, OUTPUT); 
    pinMode(STEPPER_IN2, OUTPUT); 
    pinMode(STEPPER_IN3, OUTPUT); 
    pinMode(STEPPER_IN4, OUTPUT); 

    pinMode(ENCODER_INC_A, INPUT_PULLUP);
    pinMode(ENCODER_DEC_A, INPUT_PULLUP);
    pinMode(ENCODER_INC_B, INPUT_PULLUP);
    pinMode(ENCODER_DEC_B, INPUT_PULLUP);

    attachInterrupt(digitalPinToInterrupt(ENCODER_INC_A), encoderup_A, CHANGE);
    attachInterrupt(digitalPinToInterrupt(ENCODER_DEC_A), encoderdown_A, CHANGE);
    attachInterrupt(digitalPinToInterrupt(ENCODER_INC_B), encoderup_B, CHANGE);
    attachInterrupt(digitalPinToInterrupt(ENCODER_DEC_B), encoderdown_B, CHANGE);
  
    pinMode(MOTOR_PWM_A, OUTPUT);
    pinMode(MOTOR_IN_1_A, OUTPUT);
    pinMode(MOTOR_IN_2_A, OUTPUT);

    pinMode(MOTOR_PWM_B ,OUTPUT);
    pinMode(MOTOR_IN_1_B ,OUTPUT);
    pinMode(MOTOR_IN_2_B ,OUTPUT);

    digitalWrite(MOTOR_IN_1_A, LOW); 
    digitalWrite(MOTOR_IN_2_A, HIGH);

    digitalWrite(MOTOR_IN_1_B, HIGH); 
    digitalWrite(MOTOR_IN_2_B, LOW);
    
    if(sensor_initialization()>0){
        while(1);
    }
    if(BLE_initialization()>0){
        while(1);
    }

    manage = 0;
}

void loop(){
    BLEDevice central = BLE.central();
  
    if(central){
    digitalWrite(LED_BUILTIN, HIGH);
    
    while(central.connected()){
      
        current_millis = millis();
        if(current_millis - previous_millis >= 500){
            manage = manage_short.value();
            previous_millis = current_millis;
        }
        
        if(manage == BATTERY_CONTROL){
            //readBatteryLevel();
            //readHTS();
        }else if(manage == DRIVE_CONTROL){
            set_motors();
            set_head();
            set_leds();
        }else if(manage == SPEED_CONTROL){
            change_speed();
        }else if(manage == DISTANCE_CONTROL){
            do_route();
        }else if(manage == LIVE_CONTROL){
            read_IMU();
            set_motors();
            set_head();
        }
    }
    
    off_all();    

    digitalWrite(LED_BUILTIN, LOW); 
  }
}

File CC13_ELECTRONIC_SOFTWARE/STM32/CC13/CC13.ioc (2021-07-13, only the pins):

Mcu.UserName=STM32F103C8Tx
PA0-WKUP.GPIO_Label=TIM2-1_ENC1A
PA0-WKUP.Signal=S_TIM2_CH1_ETR
PA1.GPIO_Label=TIM2-2_ENC1B
PA1.Signal=S_TIM2_CH2
PA10.GPIO_Label=TIM1-3_SER1
PA10.Signal=S_TIM1_CH3
PA11.GPIO_Label=TIM1-4_SER2
PA11.Signal=S_TIM1_CH4
PA12.GPIO_Label=PA12-EXTI12_MPU
PA12.Signal=GPXTI12
PA13.Signal=SYS_JTMS-SWDIO
PA14.Signal=SYS_JTCK-SWCLK
PA15.GPIO_Label=PA15_LED1R
PA15.Signal=GPIO_Output
PA2.GPIO_Label=USART2-TX_BT1
PA2.Signal=USART2_TX
PA3.GPIO_Label=USART2-RX_BT1
PA3.Signal=USART2_RX
PA4.Signal=ADCx_IN4
PA5.Signal=ADCx_IN5
PA6.GPIO_Label=TIM3-1_ENC2A
PA6.Signal=S_TIM3_CH1
PA7.GPIO_Label=TIM3-2_ENC2B
PA7.Signal=S_TIM3_CH2
PA8.GPIO_Label=TIM1-1_MA-PWM
PA8.Signal=S_TIM1_CH1
PA9.GPIO_Label=TIM1-2_MB-PWM
PA9.Signal=S_TIM1_CH2
PB0.GPIO_Label=PB1-AN_5.0V
PB0.Signal=ADCx_IN8
PB1.GPIO_Label=PB1-AN_3.3V
PB1.Signal=ADCx_IN9
PB10.GPIO_Label=USART3-TX_BT2
PB10.Signal=USART3_TX
PB11.GPIO_Label=USART3-RX_BT2
PB11.Signal=USART3_RX
PB12.GPIO_Label=PB12_MA-IN2
PB12.Signal=GPIO_Output
PB13.GPIO_Label=PB13_MA-IN1
PB13.Signal=GPIO_Output
PB14.GPIO_Label=PB14_MB-IN1
PB14.Signal=GPIO_Output
PB15.GPIO_Label=PB15_MB-IN2
PB15.Signal=GPIO_Output
PB3.GPIO_Label=PB3_LED1G
PB3.Signal=GPIO_Output
PB4.GPIO_Label=PB4_LED1B
PB4.Signal=GPIO_Output
PB5.GPIO_Label=PB5_LED2R
PB5.Signal=GPIO_Output
PB6.GPIO_Label=PB6_LED2G
PB6.Signal=GPIO_Output
PB7.GPIO_Label=PB7_LED2B
PB7.Signal=GPIO_Output
PB8.GPIO_Label=I2C1-SCL_MPU
PB8.Signal=I2C1_SCL
PB9.GPIO_Label=I2C1-SDA_MPU
PB9.Signal=I2C1_SDA
PC13-TAMPER-RTC.Signal=GPIO_Output
PD0-OSC_IN.Signal=RCC_OSC_IN
PD1-OSC_OUT.Signal=RCC_OSC_OUT

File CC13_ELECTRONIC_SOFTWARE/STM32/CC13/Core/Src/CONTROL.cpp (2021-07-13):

/*
 * CONTROL.cpp
 *
 *  Created on: May 2, 2020
 *      Author: Karol Janic
 */

#include <main.h>
#include <CONTROL.h>
#include <LED.h>
#include <MOTOR.h>
#include <MPU6050.h>

#include <math.h>

extern TIM_HandleTypeDef htim1;
extern TIM_HandleTypeDef htim2;
extern TIM_HandleTypeDef htim3;
extern TIM_HandleTypeDef htim4;

extern I2C_HandleTypeDef hi2c1;

extern GPIO_InitTypeDef gpio;

extern UART_HandleTypeDef huart2;
extern UART_HandleTypeDef huart3;

extern ADC_HandleTypeDef hadc1;


DigitalLED_RGB rgb1, rgb2;
ServoMotor servo1, servo2;
DCMotor motor1, motor2;
Encoder encoder1, encoder2;
I2Cdev i2cdev;
MPU6050 mpu;


uint8_t char2=0, char3=0, infoX=0, infoY=0;
float  m1Val=0, m2Val=0;
bool m1Dir=0, m2Dir=0;
float x, y;
float m1, m2;
float voltage;

uint16_t packetSize;
uint16_t fifoCount;
uint8_t fifoBuffer[64];

uint32_t supplies[3];

inline float max(float x, float y){
	if(x<0)
		x = -x;
	if(y<0)
		y = -y;
	if(x>y)
		return x;
	else
		return y;
}


inline void setup(void)
{
	rgb1.Init(GPIOA, PA15_LED1R_Pin, GPIOB, PB3_LED1G_Pin, GPIOB, PB4_LED1B_Pin);
	rgb2.Init(GPIOB, PB5_LED2R_Pin, GPIOB, PB6_LED2G_Pin, GPIOB, PB7_LED2B_Pin);
	rgb1.Off();
	rgb2.Off();

	servo1.Init(&htim1, TIM_CHANNEL_3, 0, 180, 1);	// bottom servo
	servo2.Init(&htim1, TIM_CHANNEL_4, 0, 180, 1);	// top servo
	servo1.PwmClarify(1200, 2200);
	servo2.PwmClarify(1200, 2200);
	servo1.SetNormal();
	servo2.SetNormal();

	motor1.Init(&htim1, TIM_CHANNEL_1, GPIOB, PB13_MA_IN1_Pin, GPIOB, PB12_MA_IN2_Pin, 1);
	motor2.Init(&htim1, TIM_CHANNEL_2, GPIOB, PB14_MB_IN1_Pin, GPIOB, PB15_MB_IN2_Pin, 1);
	motor1.Off();
	motor2.Off();

	encoder1.Init(&htim2, TIM_CHANNEL_1, 1920);
	encoder2.Init(&htim3, TIM_CHANNEL_1, 1920);

	HAL_GPIO_WritePin(GPIOC, GPIO_PIN_13, GPIO_PIN_RESET);

	HAL_UART_Receive_IT(&huart2, &char2, 1);
	HAL_UART_Receive_IT(&huart3, &char3, 1);

	HAL_ADC_Start(&hadc1);

	i2cdev.Init(&hi2c1);

	mpu.initialize();
	mpu.DMPInitialize();

	mpu.setFullScaleAccelerationRange(0x00);
	mpu.setFullScaleGyroscopeRange(0x00);

	mpu.setXGyroscopeOffset(0);
	mpu.setYGyroscopeOffset(0);
	mpu.setZGyroscopeOffset(0);

	mpu.setXAccelerationOffset(0);
	mpu.setYAccelerationOffset(0);
	mpu.setZAccelerationOffset(0);

	uint8_t packetSize = mpu.DMPGetFIFOPacketSize();


}

inline void loop(void){

	servo1.SetAngle(170);
	servo2.SetAngle(10);

	HAL_Delay(1000);

	servo2.SetAngle(170);
	servo1.SetAngle(10);

	HAL_Delay(1000);

}

inline void setRGB(DigitalLED_RGB *led, int info)
{
	led->On(1&info, 2&info, 4&info);
}

inline void setServos(ServoMotor *topServo, ServoMotor *bottomServo, int infoX, int infoY)
{
	x = 1.6*infoX;
	x+=10;
	topServo->SetAngleProcent((uint32_t)x);
	y = 0.9*infoY;
	y+=45;
	bottomServo->SetAngleProcent((uint32_t)y);
}

inline void setMotors(DCMotor *motorR, DCMotor *motorL, int infoX, int infoY)
{
	if(infoX == 0 && infoY == 0)
	{
		motorR->SetValue(0);
		motorR->SetDirection(1);

		motorL->SetValue(0);
		motorL->SetDirection(1);
		return;
	}

	x = 2*infoX - 100;
	if(x<0){
		x = (int)((-x)/10);
		x *= -10;
	}
	else{
		x = (int)((x)/10);
		x *= 10;
	}

	y = 2*infoY - 100;
	if(y<0){
		y = (int)((-y)/10);
		y *= -10;
	}
	else{
		y = (int)((y)/10);
		y *= 10;
	}


	if(x <= 20 && x >= -20 && y == 100){		// {12:00}
		m1 = 100;
		m2 = 100;
	}
	else if(x <= 20 && x >= -20 && y == -100){	// {6:00}
		m1 = -100;
		m2 = -100;
	}
	else if(x == 0){
	m1 = y;
	m2 = y;
	}
	else if(x == 100 && y >= -20 && y <= 20){	// {3:00}
		m1 = 50;
		m2 = -50;
	}
	else if(x == -100 && y >= -20 && y <= 20){	// {9:00}
		m1 = -50;
		m2 = 50;
	}
	else if(x >= 0 && y >= 0){
		m1 = 0.75*max(x,y);
		m2 = 0.25*max(x,y);
	}
	else if(x <= 0 && y >= 0){
		m1 = 0.25*max(x,y);
		m2 = 0.75*max(x,y);
	}
	else if(x <= 0 && y <= 0){
		m1 = -0.75*max(x,y);
		m2 = -0.25*max(x,y);
	}
	else{
		m1 = -0.25*max(x,y);
		m2 = -0.75*max(x,y);
	}

	if(m1 < 0){
		motorR->SetDirection(0);
		m1 = -m1;
		motorR->SetValue((uint8_t)m1);
	}
	else{
		motorR->SetDirection(1);
		motorR->SetValue((uint8_t)m1);
	}

	if(m2 < 0){
		motorL->SetDirection(0);
		m2 = -m2;
		motorL->SetValue((uint8_t)m2);
	}
	else{
		motorL->SetDirection(1);
		motorL->SetValue((uint8_t)m2);
	}

}

void sendSupplyVoltage(){

	uint8_t send_info[] = {100, 101, 102};
	HAL_UART_Transmit(&huart2, send_info, 3, 500);
}


inline void UART_Callback(UART_HandleTypeDef *huart){

	if(huart->Instance == USART2)
	{

		if(char2 == 10){

		}
		else if(char2 == 11){
			HAL_UART_Receive(&huart2, &infoX, 1, 5000);
			setRGB(&rgb1, infoX);
		}
		else if(char2 == 12){
			HAL_UART_Receive(&huart2, &infoX, 1, 5000);
			setRGB(&rgb2, infoX);
		}
		else if(char2 == 21)
		{
			HAL_UART_Receive(&huart2, &infoX, 1, 5000);
			HAL_UART_Receive(&huart2, &infoY, 1, 5000);
			setMotors(&motor1, &motor2, infoX, infoY);

		}
		else if(char2 == 22)
		{
			HAL_UART_Receive(&huart2, &infoX, 1, 5000);
			HAL_UART_Receive(&huart2, &infoY, 1, 5000);
			setServos(&servo2, &servo1, infoX, infoY);
		}
		else if(char2 == 51)
		{
			mpu.resetFIFO();
			fifoCount = mpu.getFIFOCount();
			while (fifoCount < packetSize)
				fifoCount = mpu.getFIFOCount();
			mpu.getFIFOBytes(fifoBuffer, packetSize);

			HAL_UART_Transmit(&huart2, &fifoBuffer[0], 1, 500);
			HAL_UART_Transmit(&huart2, &fifoBuffer[1], 1, 500);
			HAL_UART_Transmit(&huart2, &fifoBuffer[4], 1, 500);
			HAL_UART_Transmit(&huart2, &fifoBuffer[5], 1, 500);
			HAL_UART_Transmit(&huart2, &fifoBuffer[8], 1, 500);
			HAL_UART_Transmit(&huart2, &fifoBuffer[9], 1, 500);
			HAL_UART_Transmit(&huart2, &fifoBuffer[12], 1, 500);
			HAL_UART_Transmit(&huart2, &fifoBuffer[13], 1, 500);
			rgb1.Toggle();
		}

		HAL_UART_Receive_IT(&huart2, &char2, 1);
	}

	if(huart->Instance == USART3)
	{


	}
}


extern "C" {
void extern_setup(void) { setup(); }
void extern_loop(void)  { loop();  }
void extern_UART_Callback(UART_HandleTypeDef *huart)  { UART_Callback(huart); }
}

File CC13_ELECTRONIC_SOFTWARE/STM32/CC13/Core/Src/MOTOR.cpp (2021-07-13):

/*
 * MOTOR.cpp
 *
 *  Created on: May 2, 2020
 *      Author: Karol Janic
 */

#include <math.h>
#include "MOTOR.h"


/// ServoMotor

void ServoMotor::Init(TIM_HandleTypeDef *_htim, uint32_t _channel, uint32_t _angle_min, uint32_t _angle_max, bool _mode){

	htim = _htim;
	channel = _channel;

	angle_min = _angle_min;
	angle_max = _angle_max;

	pwm_min = 1000;
	pwm_max = 2000;

	mode = _mode;

	HAL_TIM_PWM_Start(htim, channel);

	SetNormal();
}

void ServoMotor::SetAngle(uint32_t angle){

	if(angle>angle_max)
		angle = angle_max;
	if(angle<angle_min)
		angle = angle_min;

	double step = double(pwm_max-pwm_min)/double(angle_max-angle_min);

	if(mode)
		pwm = uint32_t(pwm_min + (angle-angle_min)*step+0.5);
	else
		pwm = uint32_t(pwm_max - (angle-angle_min)*step-0.5);

	__HAL_TIM_SET_COMPARE(htim, channel, pwm);
}

void ServoMotor::SetAngleProcent(uint32_t procent){

	uint32_t power = procent;
	if(power<0)
		power = 0;
	if(power>100)
		power = 100;

	double step = 1.8;
	double result = step*power;

	SetAngle(result);
}

void ServoMotor::SetNormal(){

	SetAngle(uint32_t((angle_max-angle_min)/2)+0.5);
}

void ServoMotor::ChangeMode(){

	mode = !mode;
}

void ServoMotor::PwmClarify(uint32_t _pwm_min, uint32_t _pwm_max){

	pwm_min = _pwm_min;
	pwm_max = _pwm_max;
}


/// DCMotor

void DCMotor::Init(TIM_HandleTypeDef *_htim,  uint32_t _channel,
			  GPIO_TypeDef *_GPIOx_Dir1, uint16_t _GPIO_Pin_Dir1,
			  GPIO_TypeDef *_GPIOx_Dir2, uint16_t _GPIO_Pin_Dir2, bool _mode){

	htim = _htim;
	channel = _channel;
	period = htim->Init.Period;

	GPIOx_Dir1 = _GPIOx_Dir1;
	GPIO_Pin_Dir1 = _GPIO_Pin_Dir1;

	GPIOx_Dir2 = _GPIOx_Dir2;
	GPIO_Pin_Dir2 = _GPIO_Pin_Dir2;

	mode = _mode;
	currentMode = _mode;

	currentValue = 0;

	HAL_TIM_PWM_Start(htim, channel);

	Off();
}

void DCMotor::SetValue(uint8_t _value){

	value = _value;
}

void DCMotor:: ChangeDirection(){

	mode = !mode;
}

void DCMotor:: SetDirection(bool direction){

	mode = direction;
}

void DCMotor::Off(){

	HAL_GPIO_WritePin(GPIOx_Dir1, GPIO_Pin_Dir1, GPIO_PIN_RESET);
	HAL_GPIO_WritePin(GPIOx_Dir2, GPIO_Pin_Dir2, GPIO_PIN_RESET);
	__HAL_TIM_SET_COMPARE(htim, channel, 0);
}

void DCMotor::On(uint32_t power){

	if(power<0)
		power = 0;
	if(power>100)
		power = 100;

	period  = 20000;
	double value = period/100.0*power;


	if(mode){

		HAL_GPIO_WritePin(GPIOx_Dir1, GPIO_Pin_Dir1, GPIO_PIN_RESET);
		HAL_GPIO_WritePin(GPIOx_Dir2, GPIO_Pin_Dir2, GPIO_PIN_SET);
		__HAL_TIM_SET_COMPARE(htim, channel, uint32_t(value));
	}
	else {

		HAL_GPIO_WritePin(GPIOx_Dir1, GPIO_Pin_Dir1, GPIO_PIN_SET);
		HAL_GPIO_WritePin(GPIOx_Dir2, GPIO_Pin_Dir2, GPIO_PIN_RESET);
		__HAL_TIM_SET_COMPARE(htim, channel, uint32_t(value));
	}
}

void DCMotor::Update(){

	if(value == currentValue && mode == currentMode)
		return;

/*	uint8_t x;
	if(mode){
		if(value < currentValue){
			x = currentValue-10;
			if(currentValue < 10 && currentValue >= 0)
				ChangeDirection();
			if(x<value)
				x = value;
			currentValue = x;
		}
		else{
			x = currentValue+10;
			if(currentValue < 0 && currentValue >= -10)
				ChangeDirection();
			if(x>value)
				x = value;
			currentValue = x;
		}
	}

	On(currentValue);	*/

	float a,b,x;

	if(mode)
		a = value;
	else
		a = -value;

	if(currentMode)
		b = currentValue;
	else
		b = -currentValue;

	if(a < b){
		x = b-10;
		if(x<a)
			x = a;
		b = x;
	}
	else{
		x = b+10;
		if(x>a)
			x = a;
		b = x;
	}

	if(b < 0){
		currentMode = 0;
		currentValue = -b;
		SetDirection(0);
		On(-b);
	}
	else{
		currentMode = 1;
		currentValue = b;
		SetDirection(1);
		On(b);
	}

}


// Encoder

void Encoder::Init(TIM_HandleTypeDef *_htim, uint32_t first_channel, uint32_t _max_impulse){

	htim = _htim;
	channel = first_channel;
	max_impulse = _max_impulse;
	max_impulse--;

	HAL_TIM_Encoder_Start(htim, TIM_CHANNEL_ALL);
	htim -> Instance->ARR = max_impulse;
}


uint32_t Encoder::Read(){

	return HAL_TIM_ReadCapturedValue(htim, channel);
}

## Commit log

2021-05-23 Add folders
    [ModelPłytki.brd, ModelPłytki.sch]
2021-05-23 New mechanical models
    [Body1.stl, Body2.stl, Body3.stl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]
